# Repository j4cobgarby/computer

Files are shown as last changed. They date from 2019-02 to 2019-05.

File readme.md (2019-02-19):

# My computer

## A Z80 computer that I've designed, but haven't made in real life yet

Here's the schematic:

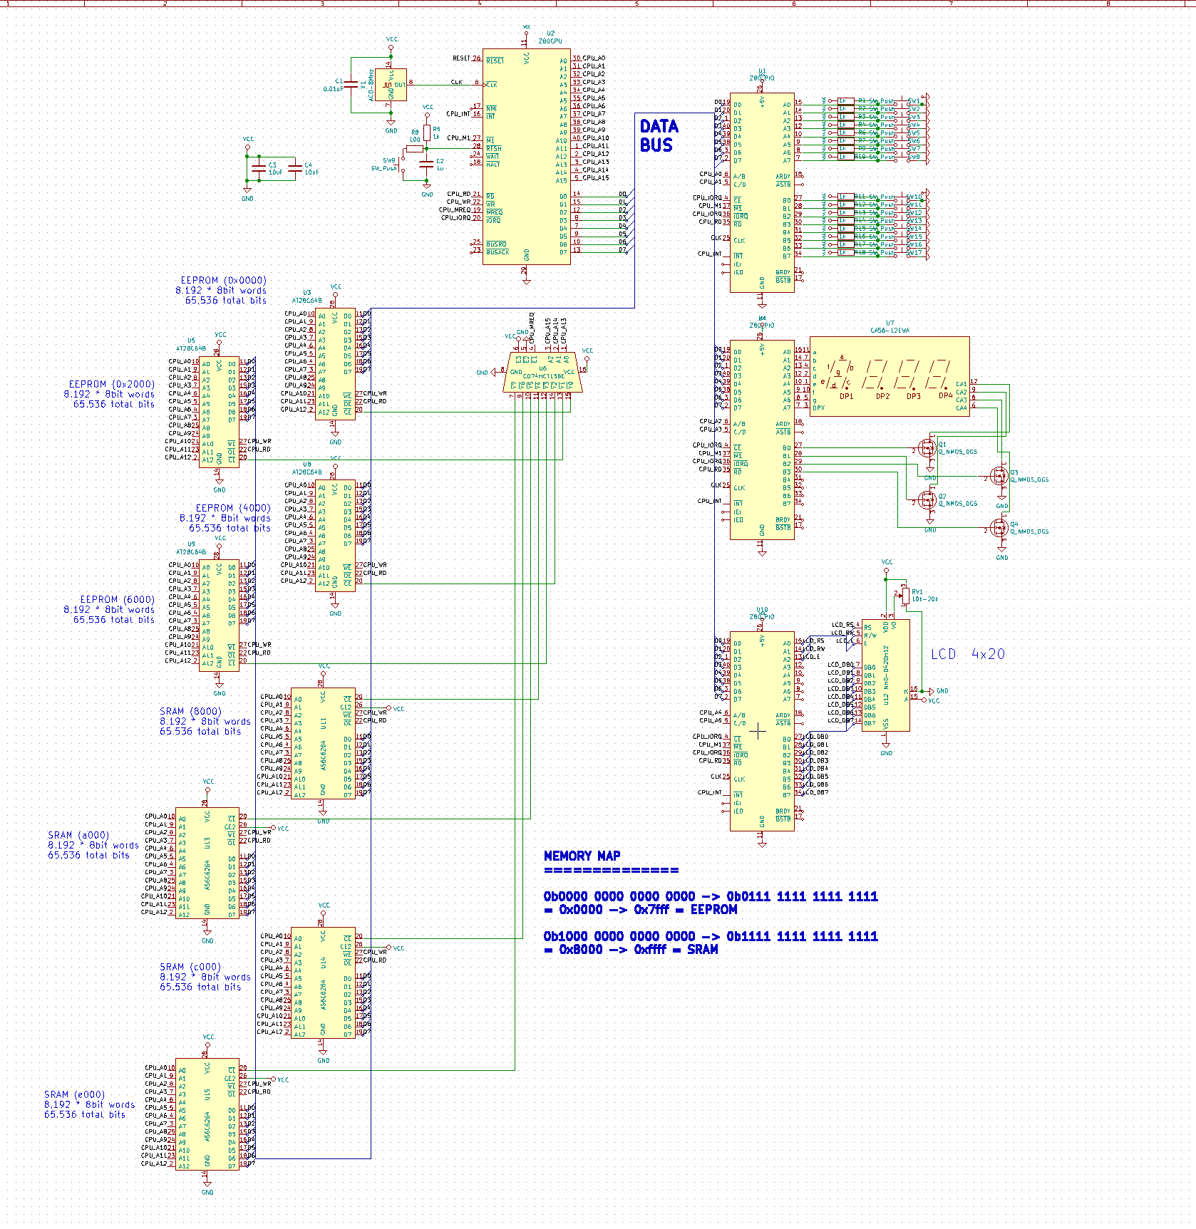
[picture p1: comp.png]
Schematic


The schematic shows 3 PIO chips to control various peripherals. In practice, I could add up to 5 more PIO chips, but since when I do implement this on a breadboard I will be able to place new components in easily, I left any extra PIO chips out of the schematic.

There are 4 EEPROM chips and 4 static RAM chips for a total of 512Kbits (64KB) of total memory. The various memory chips are enabled using a demultiplexer.

The output screen will be a 4x20 LCD display, alongside a 4-digit 7-segment display, but hobbytronics sells a really nice [VGA driver board](http://www.hobbytronics.co.uk/serial-vga) which I'm tempted to buy.

I haven't written any software for the processor yet.

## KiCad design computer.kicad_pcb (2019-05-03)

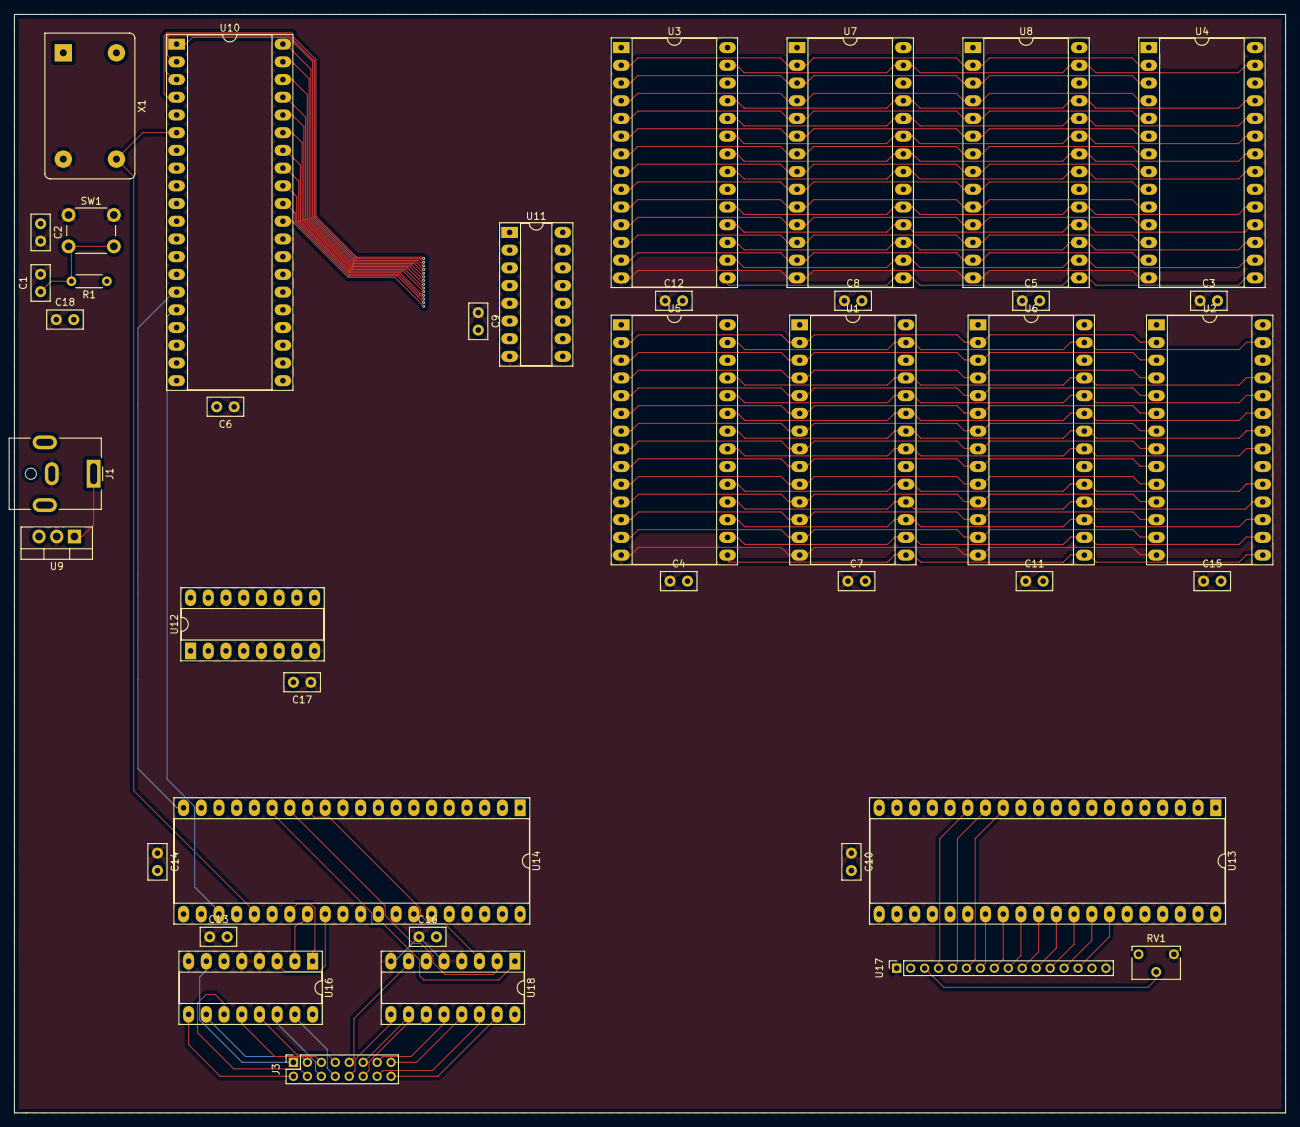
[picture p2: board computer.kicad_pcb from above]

Board: 4 copper layers, 182.2 x 157.5 mm, 41 parts (0 on the bottom side), 79 nets.

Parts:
C1: 1u; C_Disc_D5.0mm_W2.5mm_P2.50mm
C2: 0.01uF; C_Disc_D5.0mm_W2.5mm_P2.50mm
C3, C4, C5, C6, C7, C8, C9, C10, C11, C12, C13, C14, C15, C16, C17, C18: 100nF; C_Disc_D5.0mm_W2.5mm_P2.50mm
J1: Jack-DC; BarrelJack_CUI_PJ-063AH_Horizontal
J3: Conn_02x08_Counter_Clockwise; PinSocket_2x08_P2.00mm_Vertical
R1: 1k; R_Axial_DIN0204_L3.6mm_D1.6mm_P5.08mm_Horizontal
RV1: 10k-20k; Potentiometer_Bourns_3266W_Vertical
SW1: SW_Push; SW_PUSH_6mm_H4.3mm
U1, U2, U5, U6: AS6C6264; DIP-28_W15.24mm_Socket_LongPads
U3, U4, U7, U8: AT28C64B; DIP-28_W15.24mm_Socket_LongPads
U9: L7805; TO-220-3_Vertical
U10: Z80CPU; DIP-40_W15.24mm_Socket_LongPads
U11, U12: CD74HCT138E; DIP-16_W7.62mm_Socket_LongPads
U13, U14: Z80_PIO; DIP-40_W15.24mm_Socket_LongPads
U16, U18: CD74HC238E; DIP-16_W7.62mm_Socket_LongPads
U17: NHD-0420H1Z; PinSocket_1x16_P2.00mm_Vertical
X1: ACO-8MHz; Oscillator_DIP-14_LargePads

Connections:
/CLK: U10.6, U13.25, U14.25, X1.8
/CPU_A0: U1.10, U2.10, U3.10, U4.10, U5.10, U6.10, U7.10, U8.10, U10.30, U13.6, U14.6
/CPU_A1: U1.9, U2.9, U3.9, U4.9, U5.9, U6.9, U7.9, U8.9, U10.31, U13.5, U14.5
/CPU_A2: U1.8, U2.8, U3.8, U4.8, U5.8, U6.8, U7.8, U8.8, U10.32, U12.1
/CPU_A3: U1.7, U2.7, U3.7, U4.7, U5.7, U6.7, U7.7, U8.7, U10.33, U12.2
/CPU_A4: U1.6, U2.6, U3.6, U4.6, U5.6, U6.6, U7.6, U8.6, U10.34, U12.3
/CPU_A5: U1.5, U2.5, U3.5, U4.5, U5.5, U6.5, U7.5, U8.5, U10.35
/CPU_A6: U1.4, U2.4, U3.4, U4.4, U5.4, U6.4, U7.4, U8.4, U10.36
/CPU_A7: U1.3, U2.3, U3.3, U4.3, U5.3, U6.3, U7.3, U8.3, U10.37
/CPU_A8: U1.25, U2.25, U3.25, U4.25, U5.25, U6.25, U7.25, U8.25, U10.38
/CPU_A9: U1.24, U2.24, U3.24, U4.24, U5.24, U6.24, U7.24, U8.24, U10.39
/CPU_A10: U1.21, U2.21, U3.21, U4.21, U5.21, U6.21, U7.21, U8.21, U10.40
/CPU_A11: U1.23, U2.23, U3.23, U4.23, U5.23, U6.23, U7.23, U8.23, U10.1
/CPU_A12: U1.2, U2.2, U3.2, U4.2, U5.2, U6.2, U7.2, U8.2, U10.2
/CPU_A13: U10.3, U11.1
/CPU_A14: U10.4, U11.2
/CPU_A15: U10.5, U11.3
/CPU_INT: U10.16, U13.23, U14.23
/CPU_IORQ: U10.20, U13.4, U14.4
/CPU_M1: U10.27, U13.37, U14.37
/CPU_MREQ: U10.19, U11.4
/CPU_RD: U1.22, U2.22, U3.22, U4.22, U5.22, U6.22, U7.22, U8.22, U10.21, U13.35, U14.35
/CPU_WR: U1.27, U2.27, U3.27, U4.27, U5.27, U6.27, U7.27, U8.27, U10.22
/D0: U1.11, U2.11, U3.11, U4.11, U5.11, U6.11, U7.11, U8.11, U10.14, U13.19, U14.19
/D1: U1.12, U2.12, U3.12, U4.12, U5.12, U6.12, U7.12, U8.12, U10.15, U13.20, U14.20
/D2: U1.13, U2.13, U3.13, U4.13, U5.13, U6.13, U7.13, U8.13, U10.12, U13.1, U14.1
/D3: U1.15, U2.15, U3.15, U4.15, U5.15, U6.15, U7.15, U8.15, U10.8, U13.40, U14.40
/D4: U1.16, U2.16, U3.16, U4.16, U5.16, U6.16, U7.16, U8.16, U10.7, U13.39, U14.39
/D5: U1.17, U2.17, U3.17, U4.17, U5.17, U6.17, U7.17, U8.17, U10.9, U13.38, U14.38
/D6: U1.18, U2.18, U3.18, U4.18, U5.18, U6.18, U7.18, U8.18, U10.10, U13.3, U14.3
/D7: U1.19, U2.19, U3.19, U4.19, U5.19, U6.19, U7.19, U8.19, U10.13, U13.2, U14.2
GND: C1.2, C2.2, C3.1, C4.1, C5.1, C6.1, C7.1, C8.1, C9.1, C10.1, C11.1, C12.1, C13.1, C14.1, C15.1, C16.1, C17.1, C18.1, J1.2, RV1.1, SW1.1, U1.14, U2.14, U3.14, U4.14, U5.14, U6.14, U7.14, U8.14, U9.2, U10.29, U11.5, U11.8, U12.5, U12.8, U13.11, U14.11, U16.4, U16.5, U16.8, U17.1, U17.16, U18.4, U18.5, U18.8, X1.7
unnamed: C1.1, R1.2, SW1.2, U10.26
unnamed: J1.1, U9.1
unnamed: RV1.2, U17.3
unnamed: U1.20, U11.10
unnamed: U2.20, U11.7
unnamed: U6.20, U11.9
unnamed: U5.20, U11.11
unnamed: U4.20, U11.12
unnamed: U3.20, U11.13
unnamed: U8.20, U11.14
unnamed: U7.20, U11.15
unnamed: U12.13, U14.36
unnamed: U12.15, U13.36
unnamed: U13.13, U17.6
unnamed: U13.14, U17.5
unnamed: U13.15, U17.4
unnamed: U13.27, U17.7
unnamed: U13.28, U17.8
unnamed: U13.29, U17.9
unnamed: U13.30, U17.10
unnamed: U13.31, U17.11
unnamed: U13.32, U17.12
unnamed: U13.33, U17.13
unnamed: U13.34, U17.14
unnamed: U14.13, U18.3
unnamed: U14.14, U18.2
unnamed: U14.15, U18.1
unnamed: U14.27, U16.1
unnamed: U14.28, U16.2
unnamed: U14.29, U16.3
VCC: C2.1, C3.2, C4.2, C5.2, C6.2, C7.2, C8.2, C9.2, C10.2, C11.2, C12.2, C13.2, C14.2, C15.2, C16.2, C17.2, C18.2, R1.1, RV1.3, U1.26, U1.28, U2.26, U2.28, U3.28, U4.28, U5.26, U5.28, U6.26, U6.28, U7.28, U8.28, U9.3, U10.11, U11.6, U11.16, U12.6, U12.16, U13.26, U14.26, U16.6, U16.16, U17.2, U17.15, U18.6, U18.16, X1.14
kbd_in0: J3.8, U16.15
kbd_in1: J3.7, U16.13
kbd_in2: J3.6, U16.14
kbd_in3: J3.5, U16.12
kbd_in4: J3.4, U16.11
kbd_in5: J3.3, U16.10
kbd_in6: J3.2, U16.9
kbd_in7: J3.1, U16.7
kbd_out0: J3.16, U18.15
kbd_out1: J3.15, U18.13
kbd_out2: J3.14, U18.14
kbd_out3: J3.13, U18.12
kbd_out4: J3.12, U18.11
kbd_out5: J3.11, U18.10
kbd_out6: J3.10, U18.9
kbd_out7: J3.9, U18.7
